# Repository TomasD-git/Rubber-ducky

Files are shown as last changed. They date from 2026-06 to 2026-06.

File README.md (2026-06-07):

# Rubber Ducky  

## Small Rubber Ducky, supports standard rubber ducky code, with website interface.  

## Features:  
**Supports standard rubber ducky code**  
**Website interface over wifi**  
**Pretty small**  
**Wifi + Bluetooth**

<details>
<summary>How to make?</summary>
  
First buy PCB, with stencil if u dont trust your soldering skills or without if u do.
then all components in the bom, u can skip solder paste, kapton tape, hot air station if u have these, once arrived 3D print case solder 4 core cable, plug usbc into pc, flash and then just assemble and you are ready.

</details>

<details>
<summary>BOM</summary>

| Name | Purpose | Quantity | Total Cost (USD) | Distributor |
|---|---|---|---|---|
| [Hot air station](https://www.aliexpress.com/item/1005007009985561.html) | Will solder everything with this | 1 | $39.54 | Aliexpress |
| [PCB + Stencil](https://jlcpcb.com) | All components are on PCB, stencil for easier soldering | 1 | $15.00 | JLCPCB |
| [All components](https://lcsc.com) | All actual components on PCB | Depends on each part | $55.00 | LCSC |
| [4 core cable](https://www.aliexpress.com/item/1005009355432278.html) | Connects the 2 PCBs together | 1 | $4.00 | Aliexpress |
| [Solder paste](https://www.aliexpress.com/item/1005008590694612.html) | Used for soldering | 1 | $7.19 | Aliexpress |
| [Small set of hot air station nozzles](https://www.aliexpress.com/item/1005002724224923.html) | Much easier to solder with 3mm nozzle instead of the 12mm that comes with the hot air station | 1 | $5.18 | Aliexpress |
| [Kapton Tape](https://www.aliexpress.com/item/1005010348863794.html) | Covers soldered stuff so it doesn't get desoldered | 1 | $2.16 | Aliexpress |

**Estimated Total Cost: $128.07**

</details>

## Pictures:







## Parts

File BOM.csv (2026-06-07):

Name | Purpose | Quantity | Total Cost (USD) | Link | Distributor
Hot air station | Will solder everything with this | 1 | 39.54 | https://www.aliexpress.com/item/1005007009985561.html | Aliexpress
PCB + Stencil | all components are on pcb, stencil for easier soldering | 1 | 15 | https://jlcpcb.com | jlcpcb
All components | all actual components on PCB | depends on each part | 55 | https://lcsc.com | lcsc
4 core cable | conects the 2 pcbs together | 1 | 4 | https://www.aliexpress.com/item/1005009355432278.html | Aliexpress
Solder paste | Used for soldering | 1 | 7.19 | https://www.aliexpress.com/item/1005008590694612.html
Small set of hot air station nozzles | much easier to solder with 3mm nozzle instead of the 12mm that comes with the hot air station | 1 | 5.18 | https://www.aliexpress.com/item/1005002724224923.html
Kapton Tape | Covers soldered stuff, so it doesnt get desoldered | 1 | 2.16 | https://www.aliexpress.com/item/1005010348863794.html | Aliexpress
 | Total Cost | Est. | 128.07

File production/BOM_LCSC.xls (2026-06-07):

JLCPCB BOM Tool - BOM Matching
BOM name：bom-JLCPCB Assembly Order-JLCPCB Assembly Order.xlsx |  |  | Download Time：2026-06-07 18:28:33 |  |  |  | * Our matching results are updated in real-time, but stock and prices may change. If it's been over 24 hours, please re-match before placing your order.
PCB Assembled Qty：5 |  |  | Est. Total Price：62.2239
Your BOM |  |  |  |  | Matched Parts |  |  |  |  |  |  | Order Information
Top Designator | Bottom Designator | Comment | Footprint | JLCPCB Part # | Matches | Part # | Manufacturer | Footprint | Description | Category | Warning | JLCPCB Part # | Product link | Lib Type | Qty | Source | Total Price ($)
AE1 |  | 2450AT18A100E | ANT-SMD_L3.2-W1.6 |  | Select by System | 2450AT18A100E | Johanson Dielectrics | 1206 | -40℃~+125℃ 0.5dBi 1.3mm 1.6mm 2.4GHz 2W 3.2mm 50Ω Patch Antenna SMA 1206 Antennas ROHS | Antennas |  | C89334 | https://jlcpcb.com/partdetail/JohansonDielectrics-2450AT18A100E/C89334 | Extended | 5 | 5 JLCPCB | 2.613
 | C10,C14,C3,C4,C7 | 1uF | 0805 |  | Select by System | CL21B105KBFNNNE | Samsung Electro-Mechanics | 0805 | 1uF 50V X7R ±10% 0805 Multilayer Ceramic Capacitors MLCC - SMD/SMT ROHS | Multilayer Ceramic Capacitors MLCC - SMD/SMT |  | C28323 | https://jlcpcb.com/partdetail/29074-CL21B105KBFNNNE/C28323 | Basic | 35 | 35 JLCPCB | 0.665
 | C15,C8,C9 | 10uF | 1206 |  | Select by System | CL31A106KBHNNNE | Samsung Electro-Mechanics | 1206 | 10uF 50V X5R ±10% 1206 Multilayer Ceramic Capacitors MLCC - SMD/SMT ROHS | Multilayer Ceramic Capacitors MLCC - SMD/SMT |  | C13585 | https://jlcpcb.com/partdetail/14236-CL31A106KBHNNNE/C13585 | Basic | 19 | 19 JLCPCB | 1.7385
 | C17 | 10nF | 0402 |  | Select by System | CL05B103KB5NNNC | Samsung Electro-Mechanics | 0402 | 10nF 50V X7R ±10% 0402 Multilayer Ceramic Capacitors MLCC - SMD/SMT ROHS | Multilayer Ceramic Capacitors MLCC - SMD/SMT |  | C15195 | https://jlcpcb.com/partdetail/15869-CL05B103KB5NNNC/C15195 | Basic | 20 | 20 JLCPCB | 0.038
C18,C19 |  | 12pF | 0402 |  | Select by System | 0402CG120J500NT | FH (Guangdong Fenghua Advanced Tech) | 0402 | 12pF 50V C0G ±5% 0402 Multilayer Ceramic Capacitors MLCC - SMD/SMT ROHS | Multilayer Ceramic Capacitors MLCC - SMD/SMT |  | C1547 | https://jlcpcb.com/partdetail/1899-0402CG120J500NT/C1547 | Basic | 20 | 20 JLCPCB | 0.034
C20,C21 |  | 1.5pF | 0402 |  | Select by System | 0402CG1R5C500NT | FH (Guangdong Fenghua Advanced Tech) | 0402 | 1.5pF 50V C0G 0402 Multilayer Ceramic Capacitors MLCC - SMD/SMT ROHS | Multilayer Ceramic Capacitors MLCC - SMD/SMT |  | C1552 | https://jlcpcb.com/partdetail/1904-0402CG1R5C500NT/C1552 | Extended | 20 | 20 JLCPCB | 0.034
C22 |  | 1.2pF | 0402 |  | Select by System | 0402CG1R2C500NT | FH (Guangdong Fenghua Advanced Tech) | 0402 | 1.2pF 50V C0G 0402 Multilayer Ceramic Capacitors MLCC - SMD/SMT ROHS | Multilayer Ceramic Capacitors MLCC - SMD/SMT |  | C1551 | https://jlcpcb.com/partdetail/1903-0402CG1R2C500NT/C1551 | Extended | 20 | 20 JLCPCB | 0.032
C23 |  | 0.5pF | 0402 |  | Select by System | 0402CG0R5C500NT | FH (Guangdong Fenghua Advanced Tech) | 0402 | 0.5pF 50V C0G 0402 Multilayer Ceramic Capacitors MLCC - SMD/SMT ROHS | Multilayer Ceramic Capacitors MLCC - SMD/SMT |  | C1544 | https://jlcpcb.com/partdetail/1896-0402CG0R5C500NT/C1544 | Extended | 20 | 20 JLCPCB | 0.022
C24 |  | 100uF | 1210 |  | Select by System | 1210X107M100NT | FH (Guangdong Fenghua Advanced Tech) | 1210 | 100uF 10V X5R ±20% 1210 Multilayer Ceramic Capacitors MLCC - SMD/SMT ROHS | Multilayer Ceramic Capacitors MLCC - SMD/SMT |  | C19269967 | https://jlcpcb.com/partdetail/20533754-1210X107M100NT/C19269967 | Extended | 5 | 5 JLCPCB | 2.46
C25 | C1,C11,C12,C13,C16,C2,C5,C6 | 100nF | 0603 |  | Select by System | CC0603KRX7R9BB104 | YAGEO | 0603 | 100nF 50V X7R ±10% 0603 Multilayer Ceramic Capacitors MLCC - SMD/SMT ROHS | Multilayer Ceramic Capacitors MLCC - SMD/SMT |  | C14663 | https://jlcpcb.com/partdetail/YAGEO-CC0603KRX7R9BB104/C14663 | Basic | 70 | 70 JLCPCB | 1.827
 | L1 | 2nH | 0402 |  | Select by System | LQG15HS2N0S02D | Murata Electronics | 0402 | 2nH 6GHz 8@100MHz 900mA 90mΩ 0402 Inductors (SMD) ROHS | Inductors (SMD) |  | C18216 | https://jlcpcb.com/partdetail/MurataElectronics-LQG15HS2N0S02D/C18216 | Extended | 20 | 20 JLCPCB | 0.234
L2 |  | 24nH | 0603 |  | Select by System | VHF160808H24NJT | FH (Guangdong Fenghua Advanced Tech) | 0603 | 12@100MHz 24nH 2GHz 300mA 600mΩ Multilayer inductor、High-frequency inductor ±5% 0603 Inductors (SMD) ROHS | Inductors (SMD) |  | C139271 | https://jlcpcb.com/partdetail/150592-VHF160808H24NJT/C139271 | Extended | 20 | 20 JLCPCB | 0.288
L3 |  | 2.7nH | 0402 |  | Select by System | MLG1005S2N7BT000 | TDK | 0402 | 2.7nH 6GHz 7@100MHz 800mA 80mΩ Multilayer inductor 0402 Inductors (SMD) ROHS | Inductors (SMD) |  | C275282 | https://jlcpcb.com/partdetail/TDK-MLG1005S2N7BT000/C275282 | Extended | 20 | 20 JLCPCB | 0.218
L4 |  | 3.9nH | 0402 |  | Select by System | SDCL1005C3N9STDF | Sunlord | 0402 | 200mΩ 3.9nH 300mA 4GHz 8@100MHz Multilayer inductor 0402 Inductors (SMD) ROHS | Inductors (SMD) |  | C14033 | https://jlcpcb.com/partdetail/Sunlord-SDCL1005C3N9STDF/C14033 | Extended | 20 | 20 JLCPCB | 0.118
R1 |  | 5.1K | 0805 |  | Unconfirmed | 0805W8F5101T5E | UNI-ROYAL(Uniroyal Elec) | 0805 | -55℃~+155℃ 125mW 150V 5.1kΩ Thick Film Resistor ±1% ±100ppm/℃ 0805 Chip Resistor - Surface Mount ROHS | Chip Resistor - Surface Mount | 1.The comment (0805W8F5101T5E) of this part does not match the one (5.1K) provided in your BOM. Please confirm; | C27834 | https://jlcpcb.com/partdetail/28584-0805W8F5101T5E/C27834 | Basic | 20 | 20 JLCPCB | 0.054
R2,R3 |  | 22 | 0603 |  | Unconfirmed | 0603WAF220JT5E | UNI-ROYAL(Uniroyal Elec) | 0603 | -55℃~+155℃ 100mW 22Ω 75V Thick Film Resistor ±1% ±100ppm/℃ 0603 Chip Resistor - Surface Mount ROHS | Chip Resistor - Surface Mount | 1.The comment (0603WAF220JT5E) of this part does not match the one (22) provided in your BOM. Please confirm; | C23345 | https://jlcpcb.com/partdetail/24078-0603WAF220JT5E/C23345 | Basic | 20 | 20 JLCPCB | 0.032
 | R10,R12,R13,R4,R5 | 10K | 0805 |  | Unconfirmed | 0805W8F1002T5E | UNI-ROYAL(Uniroyal Elec) | 0805 | -55℃~+155℃ 10kΩ 125mW 150V Thick Film Resistor ±1% ±100ppm/℃ 0805 Chip Resistor - Surface Mount ROHS | Chip Resistor - Surface Mount | 1.The comment (0805W8F1002T5E) of this part does not match the one (10K) provided in your BOM. Please confirm; | C17414 | https://jlcpcb.com/partdetail/18102-0805W8F1002T5E/C17414 | Basic | 35 | 35 JLCPCB | 0.1015
 | U1 | W25Q32JVSSIQ_C179173 | SOIC-8_L5.3-W5.3-P1.27-LS8.0-BL |  | Select by System | W25Q32JVSSIQ | Winbond Elec | SOIC-8-208mil | -40℃~+85℃ 100,000 cycles 133MHz 1uA 2.7V~3.6V 20 Years 32Mbit 3ms SPI SOIC-8-208mil NOR FLASH ROHS | NOR FLASH |  | C179173 | https://jlcpcb.com/partdetail/WinbondElec-W25Q32JVSSIQ/C179173 | Extended | 5 | 5 JLCPCB | 8.2085
U2 |  | ESP32-S3 | QFN-56-1EP_7x7mm_P0.4mm_EP5.6x5.6mm |  | Select by System | ESP32-S3 | Espressif Systems | QFN-56-EP(7x7) | -40℃~+105℃ -98.4dBm 150Mbps 2.412GHz~2.484GHz 2.4GHz 21dBm 340mA 3V~3.6V 88mA SPI、USB、UART、ADC、I2C、I2S、PWM WiFi transceiver QFN-56-EP(7x7) RF Transceiver ICs ROHS | RF Transceiver ICs |  | C2913192 | https://jlcpcb.com/partdetail/EspressifSystems-ESP32S3/C2913192 | Extended | 5 | 5 JLCPCB | 15.259
 | U3 | RT9013-33GB | SOT-23-5_L3.0-W1.7-P0.95-LS2.8-BL |  | Select by System | RT9013-33GB | Richtek Tech | SOT-23-5 | -40℃~+125℃@(Tj) 1 25uA 3.3V 30uVrms 400mV@(500mA) 5.5V 500mA 50dB@(10kHz) Fixed Over Current Protection、Over Temperature Protection、Enable Positive SOT-23-5 Voltage Regulators - Linear, Low Drop Out (LDO) Regulators ROHS | Voltage Regulators - Linear, Low Drop Out (LDO) Regulators |  | C47773 | https://jlcpcb.com/partdetail/RichtekTech-RT901333GB/C47773 | Extended | 7 | 7 JLCPCB | 0.9471
U4 |  | XUSM-0930-2319 | USB-A-SMD_XUSM-0930-2319 |  | Select by System | XUSM-0930-2319 | Lian Xin Technology | SMD | -40℃~+85℃ 1 18.75mm 36V 3A 9P Male Surface Mount, Right Angle Type-A USB 3.0 SMD USB Connectors ROHS | USB Connectors |  | C7527682 | https://jlcpcb.com/partdetail/Lian_XinTechnology-XUSM_09302319/C7527682 | Extended | 5 | 5 JLCPCB | 1.216
U6,U8 |  | SS24FL_C894433 | SOD-123FL_L2.8-W1.8-LS3.6-RD |  | Select by System | SS24FL | onsemi | SOD-123F | -55℃~+125℃ 1 Independent 100uA@40V 2A 40V 50A 550mV@2A SOD-123F Schottky Diodes ROHS | Schottky Diodes |  | C894433 | https://jlcpcb.com/partdetail/onsemi-SS24FL/C894433 | Extended | 10 | 10 JLCPCB | 1.72
U7 |  | W25Q256JVEIQTR | WSON-8_L8.0-W6.10-P1.27-BL-EP |  | Select by System | W25Q256JVEIQ | Winbond Elec | WSON-8-EP(6x8) | -40℃~+85℃ 100,000 cycles 10uA 120ms@(32KB) 133MHz 2.7V~3.6V 20 Years 256Mbit 700us SPI WSON-8-EP(6x8) NOR FLASH ROHS | NOR FLASH |  | C97522 | https://jlcpcb.com/partdetail/WinbondElec-W25Q256JVEIQ/C97522 | Extended | 5 | 5 JLCPCB | 21.12
USB2 |  | GT-USB-8016B | USB-SMD_GT-USB-8016B |  | Select by System | GT-USB-8016B | G-Switch | SMD | -40℃~+85℃ 0.15mm 1 10,000 Cycles 12.2mm 12P Black Laminated board Male Type-C USB 2.0 SMD USB Connectors ROHS | USB Connectors |  | C3001295 | https://jlcpcb.com/partdetail/GSwitch-GT_USB8016B/C3001295 | Extended | 5 | 5 JLCPCB | 2.581
Y1 |  | 40MHz | Crystal_SMD_3225-4Pin_3.2x2.5mm_HandSoldering |  | Select by Customer | HY40MSMD3225GB1R30 | Huiyuan crystal | SMD3225-4P | -40℃~+85℃ 15pF 40MHz 40Ω Crystal Oscillator ±10ppm ±30ppm SMD3225-4P Crystals ROHS | Crystals |  | C5265885 | https://jlcpcb.com/partdetail/Huiyuancrystal-HY40MSMD3225GB1R30/C5265885 | Extended | 9 | 9 JLCPCB | 0.6633

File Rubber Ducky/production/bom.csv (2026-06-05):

Designator | Footprint | Quantity | Value | LCSC Part #
AE1 | ANT-SMD_L3.2-W1.6 | 1 | 2450AT18A100E | C89334
C1, C11, C12, C13, C16, C2, C25, C5, C6 | 0603 | 9 | 100nF
C10, C14, C3, C4, C7 | 0805 | 5 | 1uF
C15, C8, C9 | 1206 | 3 | 10uF
C17 | 0402 | 1 | 10nF
C18, C19 | 0402 | 2 | 12pF
C20, C21 | 0402 | 2 | 1.5pF
C22 | 0402 | 1 | 1.2pF
C23 | 0402 | 1 | 0.5pF
C24 | 1210 | 1 | 100uF
L1 | 0402 | 1 | 2nH
L2 | 0603 | 1 | 24nH
L3 | 0402 | 1 | 2.7nH
L4 | 0402 | 1 | 3.9nH
R1 | 0805 | 1 | 5.1K
R10, R12, R13, R4, R5 | 0805 | 5 | 10K
R2, R3 | 0603 | 2 | 22
U1 | SOIC-8_L5.3-W5.3-P1.27-LS8.0-BL | 1 | W25Q32JVSSIQ_C179173 | C179173
U2 | QFN-56-1EP_7x7mm_P0.4mm_EP5.6x5.6mm | 1 | ESP32-S3
U3 | SOT-23-5_L3.0-W1.7-P0.95-LS2.8-BL | 1 | RT9013-33GB | C47773
U4 | USB-A-SMD_XUSM-0930-2319 | 1 | XUSM-0930-2319 | C7527682
U6, U8 | SOD-123FL_L2.8-W1.8-LS3.6-RD | 2 | SS24FL_C894433 | C894433
U7 | WSON-8_L8.0-W6.10-P1.27-BL-EP | 1 | W25Q256JVEIQTR | C97522
USB2 | USB-SMD_GT-USB-8016B | 1 | GT-USB-8016B | C3001295
Y1 | Crystal_SMD_3225-4Pin_3.2x2.5mm_HandSoldering | 1 | 40MHz

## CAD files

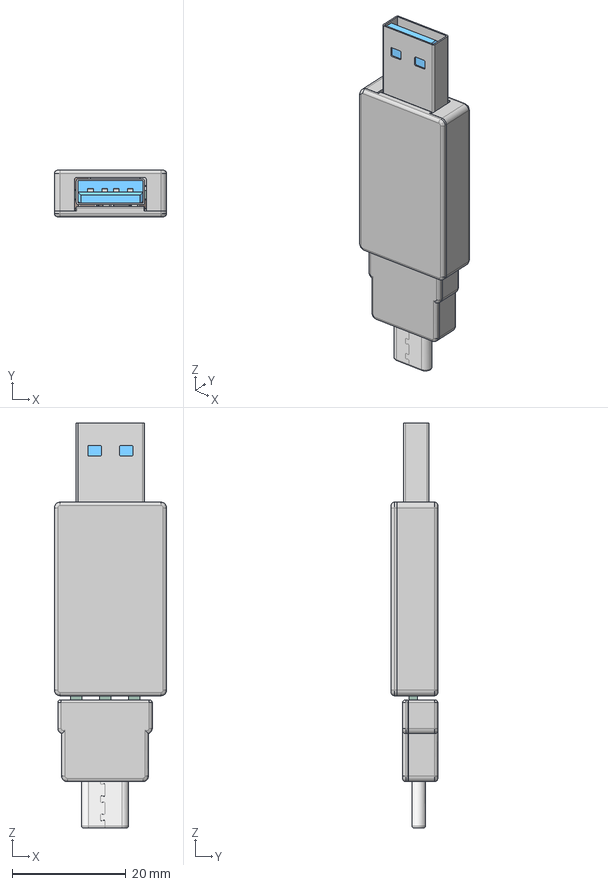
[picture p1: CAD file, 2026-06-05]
CAD/Full_Rubber_Ducky.step
19.7 x 8.21 x 71.1 mm
Crystal_SMD_3225-4Pin_3.2x2.5mm
WSON-8_L8.0-W6.0-H0.78-P1.27
C_0402_1005Metric x 7
C_1210_3225Metric
QFN-56-1EP_7x7mm_P0.4mm_EP5.6x5.6mm
R_0603_1608Metric x 2
R_0805_2012Metric x 6
L_0603_1608Metric
USB-A-SMD_XUSM-0930-2319
SOD-123FL_L2.8-W1.8-LS3.6-RD x 2
L_0402_1005Metric x 3
ANT-SMD_L3.2-W1.6-H1.3
C_0603_1608Metric x 9
USB-SMD_GT-USB-8016B
SOT-23-5_L2.9-W1.6-H1.1-LS2.8-P0.95
C_0805_2012Metric x 5
SOIC-8_L5.3-W5.3-H1.9-LS7.9-P1.27
C_1206_3216Metric x 3
Metal Ducky_PCB

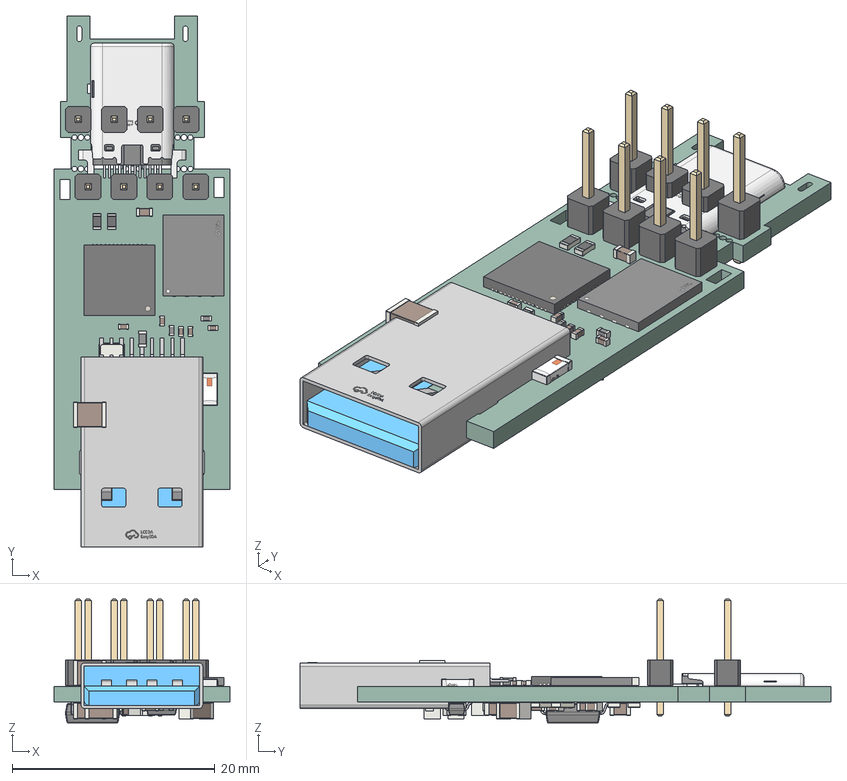
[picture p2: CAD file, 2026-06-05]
CAD/Rubber ducky_PCB.step
17.3 x 52.3 x 12.2 mm
Crystal_SMD_3225-4Pin_3.2x2.5mm
PinHeader_1x01_P2.54mm_Vertical x 8
WSON-8_L8.0-W6.0-H0.78-P1.27
C_0402_1005Metric x 7
C_1210_3225Metric
QFN-56-1EP_7x7mm_P0.4mm_EP5.6x5.6mm
R_0603_1608Metric x 2
R_0805_2012Metric x 6
L_0603_1608Metric
USB-A-SMD_XUSM-0930-2319
SOD-123FL_L2.8-W1.8-LS3.6-RD x 2
L_0402_1005Metric x 3
ANT-SMD_L3.2-W1.6-H1.3
C_0603_1608Metric x 9
USB-SMD_GT-USB-8016B
SOT-23-5_L2.9-W1.6-H1.1-LS2.8-P0.95
C_0805_2012Metric x 5
SOIC-8_L5.3-W5.3-H1.9-LS7.9-P1.27
C_1206_3216Metric x 3
Metal Ducky_PCB

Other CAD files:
CAD/Full_Rubber_Ducky.f3z

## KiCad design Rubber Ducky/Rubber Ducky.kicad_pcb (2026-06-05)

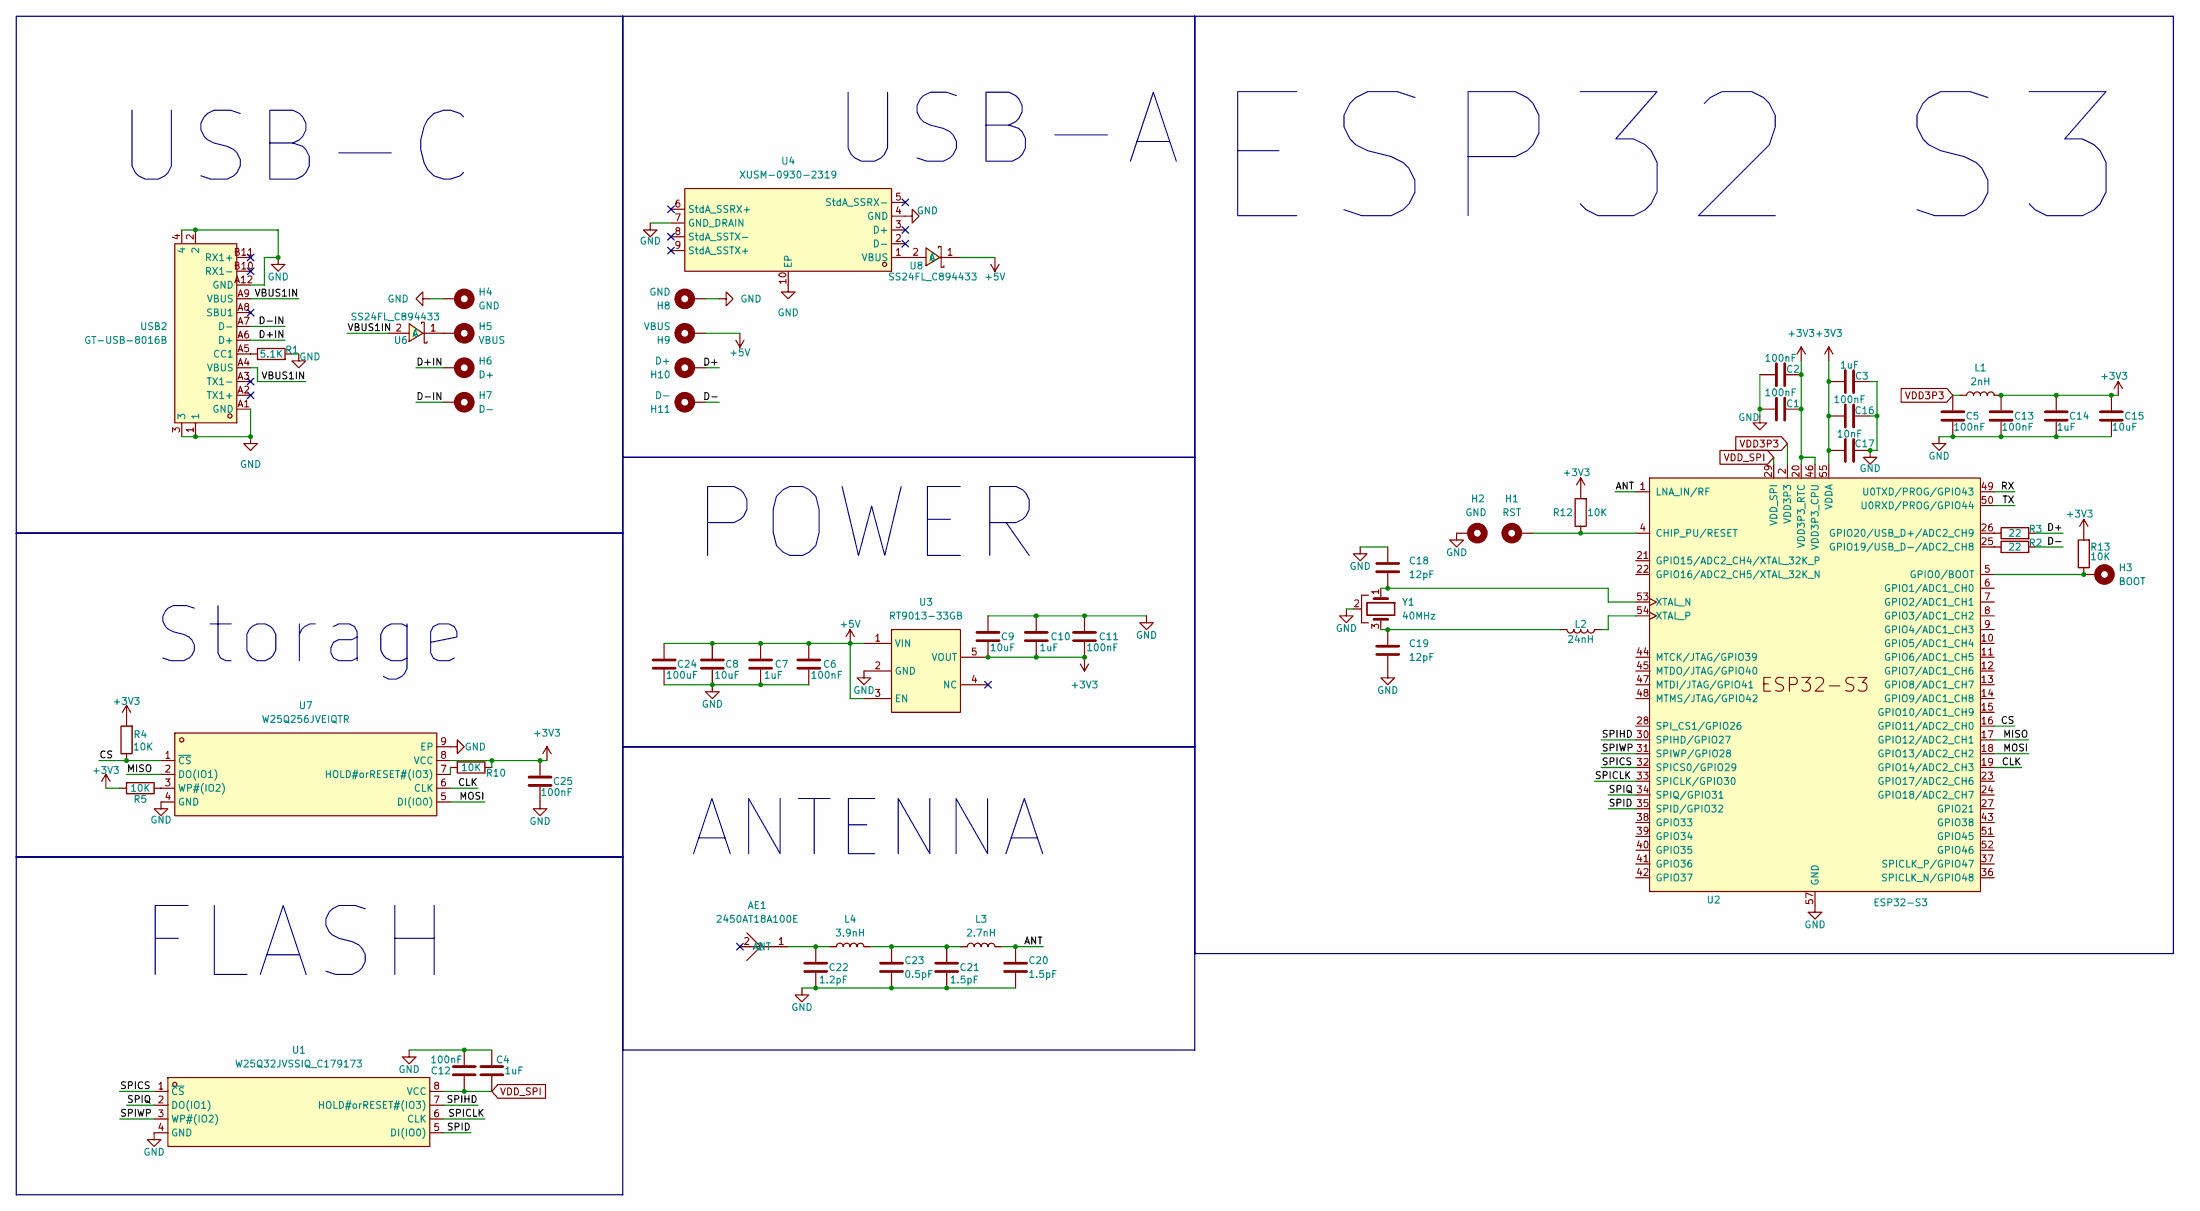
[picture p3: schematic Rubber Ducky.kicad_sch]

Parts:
AE1: 2450AT18A100E; ANT-SMD_L3.2-W1.6; MPN 2450AT18A100E; LCSC Part C89334
C1, C2, C5, C6, C11, C12, C13, C16, C25: 100nF; C_0603_1608Metric_Pad1.08x0.95mm_HandSolder
C3, C4, C7: 1uF; C_0805_2012Metric
C8, C9, C15: 10uF; C_1206_3216Metric
C10, C14: 1uF; C_0805_2012Metric_Pad1.18x1.45mm_HandSolder
C17: 10nF; C_0402_1005Metric_Pad0.74x0.62mm_HandSolder
C18, C19: 12pF; C_0402_1005Metric_Pad0.74x0.62mm_HandSolder
C20, C21: 1.5pF; C_0402_1005Metric_Pad0.74x0.62mm_HandSolder
C22: 1.2pF; C_0402_1005Metric_Pad0.74x0.62mm_HandSolder
C23: 0.5pF; C_0402_1005Metric_Pad0.74x0.62mm_HandSolder
C24: 100uF; C_1210_3225Metric
H1: RST; TestPoint_Pad_1.0x1.0mm
H2: GND; TestPoint_Pad_1.0x1.0mm
H3: BOOT; TestPoint_Pad_1.0x1.0mm
H4, H8: GND; PinHeader_1x01_P2.54mm_Vertical
H5, H9: VBUS; PinHeader_1x01_P2.54mm_Vertical
H6, H10: D+; PinHeader_1x01_P2.54mm_Vertical
H7, H11: D-; PinHeader_1x01_P2.54mm_Vertical
L1: 2nH; L_0402_1005Metric_Pad0.77x0.64mm_HandSolder
L2: 24nH; L_0603_1608Metric_Pad1.05x0.95mm_HandSolder
L3: 2.7nH; L_0402_1005Metric_Pad0.77x0.64mm_HandSolder
L4: 3.9nH; L_0402_1005Metric_Pad0.77x0.64mm_HandSolder
R1: 5.1K; R_0805_2012Metric
R2, R3: 22; R_0603_1608Metric_Pad0.98x0.95mm_HandSolder
R4, R5, R10, R12, R13: 10K; R_0805_2012Metric
U1: W25Q32JVSSIQ_C179173; SOIC-8_L5.3-W5.3-P1.27-LS8.0-BL; MPN W25Q32JVSSIQ; LCSC Part C179173
U2: ESP32-S3; QFN-56-1EP_7x7mm_P0.4mm_EP5.6x5.6mm
U3: RT9013-33GB; SOT-23-5_L3.0-W1.7-P0.95-LS2.8-BL; MPN RT9013-33GB; LCSC Part C47773
U4: XUSM-0930-2319; USB-A-SMD_XUSM-0930-2319; MPN XUSM-0930-2319; LCSC Part C7527682
U6, U8: SS24FL_C894433; SOD-123FL_L2.8-W1.8-LS3.6-RD; MPN SS24FL; LCSC Part C894433
U7: W25Q256JVEIQTR; WSON-8_L8.0-W6.10-P1.27-BL-EP; MPN W25Q256JVEIQ; LCSC Part C97522
USB2: GT-USB-8016B; USB-SMD_GT-USB-8016B; MPN GT-USB-8016B; LCSC Part C3001295
Y1: 40MHz; Crystal_SMD_3225-4Pin_3.2x2.5mm_HandSoldering

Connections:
+3V3: C1.2, C2.2, C3.1, C9.2, C10.2, C11.2, C13.1, C14.1, C15.1, C16.1, C17.1, C25.1, L1.2, R4.2, R5.2, R10.1, R12.2, R13.2, U2.20 (VDD3P3_RTC), U2.46 (VDD3P3_CPU), U2.55 (VDDA), U2.56 (VDDA), U3.5 (VOUT), U7.8 (VCC)
+5V: C6.1, C7.1, C8.1, C24.1, H9.1, U3.1 (VIN), U3.3 (EN), U8.1 (C)
/ANT: C20.1, L3.2, U2.1 (LNA_IN/RF)
/CLK: U2.19 (GPIO14/ADC2_CH3), U7.6 (CLK)
/CS: R4.1, U2.16 (GPIO11/ADC2_CH0), U7.1 (~CS)
/D+: H10.1, R3.2
/D+IN: H6.1, USB2.A6 (D+)
/D-: H11.1, R2.2
/D-IN: H7.1, USB2.A7 (D-)
/MISO: U2.17 (GPIO12/ADC2_CH1), U7.2 (DO(IO1))
/MOSI: U2.18 (GPIO13/ADC2_CH2), U7.5 (DI(IO0))
/RX: U2.49 (U0TXD/PROG/GPIO43)
/SPICLK: U1.6 (CLK), U2.33 (SPICLK/GPIO30)
/SPICS: U1.1 (~CS), U2.32 (SPICS0/GPIO29)
/SPID: U1.5 (DI(IO0)), U2.35 (SPID/GPIO32)
/SPIHD: U1.7 (HOLD#orRESET#(IO3)), U2.30 (SPIHD/GPIO27)
/SPIQ: U1.2 (DO(IO1)), U2.34 (SPIQ/GPIO31)
/SPIWP: U1.3 (WP#(IO2)), U2.31 (SPIWP/GPIO28)
/TX: U2.50 (U0RXD/PROG/GPIO44)
/VBUS1IN: U6.2 (A), USB2.A4 (VBUS), USB2.A9 (VBUS)
GND: C1.1, C2.1, C3.2, C4.2, C5.2, C6.2, C7.2, C8.2, C9.1, C10.1, C11.1, C12.2, C13.2, C14.2, C15.2, C16.2, C17.2, C18.1, C19.2, C20.2, C21.2, C22.2, C23.2, C24.2, C25.2, H2.1, H4.1, H8.1, R1.2, U1.4 (GND), U2.57 (GND), U3.2 (GND), U4.4 (GND), U4.7 (GND_DRAIN), U4.10 (EP), U7.4 (GND), U7.9 (EP), USB2.1, USB2.2, USB2.3, USB2.4, USB2.A1 (GND), USB2.A12 (GND), Y1.2
unnamed: AE1.1 (ANT), C22.1, L4.1
unnamed: C19.1, L2.2, Y1.3
unnamed: C21.1, C23.1, L3.1, L4.2
unnamed: H1.1, R12.1, U2.4 (CHIP_PU/RESET)
unnamed: H3.1, R13.1, U2.5 (GPIO0/BOOT)
unnamed: R2.1, U2.25 (GPIO19/USB_D-/ADC2_CH8)
unnamed: R3.1, U2.26 (GPIO20/USB_D+/ADC2_CH9)
unnamed: C18.2, U2.53 (XTAL_N), Y1.1
unnamed: L2.1, U2.54 (XTAL_P)
unnamed: U4.1 (VBUS), U8.2 (A)
unnamed: H5.1, U6.1 (C)
unnamed: R10.2, U7.7 (HOLD#orRESET#(IO3))
unnamed: R5.1, U7.3 (WP#(IO2))
unnamed: R1.1, USB2.A5 (CC1)
VDD3P3: C5.1, L1.1, U2.2 (VDD3P3), U2.3 (VDD3P3)
VDD_SPI: C4.1, C12.1, U1.8 (VCC), U2.29 (VDD_SPI)

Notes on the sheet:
Storage
ANTENNA
USB-C
POWER
ESP32 S3
USB-A
FLASH

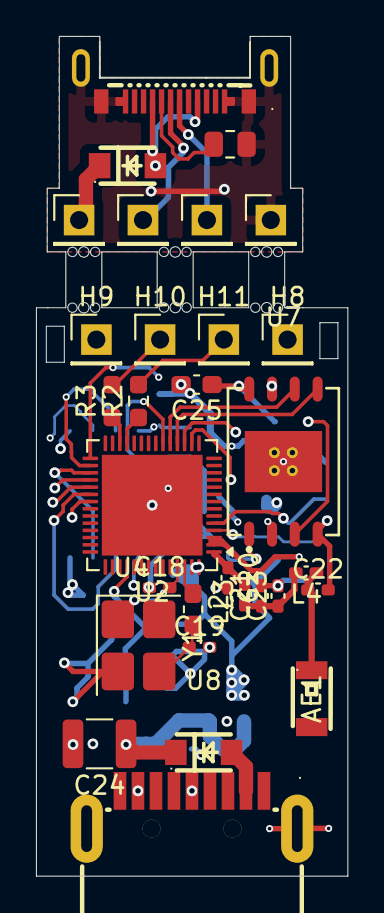
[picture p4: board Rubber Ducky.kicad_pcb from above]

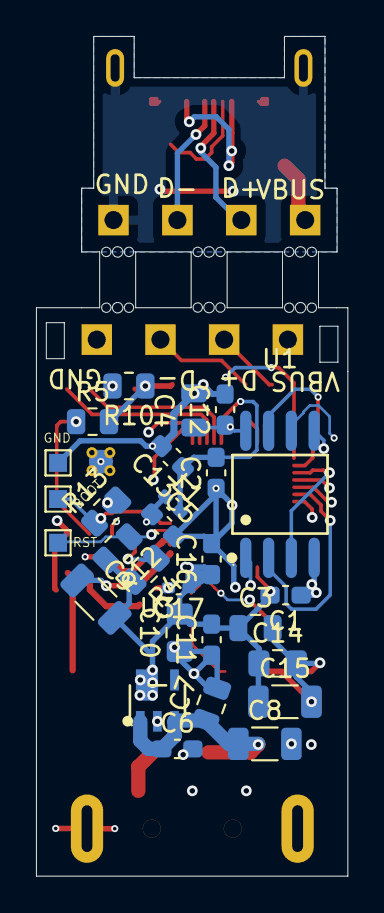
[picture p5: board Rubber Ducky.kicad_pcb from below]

Board: 4 copper layers, 17.3 x 46.6 mm, 58 parts (28 on the bottom side), 35 nets.

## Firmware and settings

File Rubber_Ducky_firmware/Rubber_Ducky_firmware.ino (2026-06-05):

#include <WiFi.h>
#include <WebServer.h>
#include <SPIFFS.h>
#include <Preferences.h>
#include <ArduinoJson.h>
#include <USB.h>
#include <USBHIDKeyboard.h>

WebServer server(80);
Preferences prefs;
USBHIDKeyboard keyboard;

bool scriptRunning = false;
unsigned long scriptStartTime = 0;

struct Config {
  char ssid[32];
  char password[32];
  char deviceName[32];
  bool apMode;
  int apChannel;
  uint16_t defaultDelay;
} config;

const char* AP_SSID_DEFAULT = "RubberDucky";
const char* AP_PASSWORD_DEFAULT = "12345678";
const int AP_CHANNEL_DEFAULT = 6;
const int AP_MAX_CONNECTIONS = 1;

// USB HID KEYBOARD SETUP
void initUSBHID() {
  keyboard.begin();
  USB.manufacturerName("Microsoft");
  USB.productName("USB Keyboard");
  USB.begin();
  Serial.println("[USB] HID Keyboard initialized");
}

struct KeyInfo {
  const char* name;
  uint8_t keycode;
  bool isSpecial; 
};

const KeyInfo specialKeys[] = {
  {"ENTER", KEY_RETURN, true},
  {"RETURN", KEY_RETURN, true},
  {"SPACE", ' ', false},
  {"TAB", KEY_TAB, true},
  {"BACKSPACE", KEY_BACKSPACE, true},
  {"DELETE", KEY_DELETE, true},
  {"INSERT", KEY_INSERT, true},
  {"HOME", KEY_HOME, true},
  {"END", KEY_END, true},
  {"PAGEUP", KEY_PAGE_UP, true},
  {"PAGE_UP", KEY_PAGE_UP, true},
  {"PAGEDOWN", KEY_PAGE_DOWN, true},
  {"PAGE_DOWN", KEY_PAGE_DOWN, true},
  {"UP", KEY_UP_ARROW, true},
  {"DOWN", KEY_DOWN_ARROW, true},
  {"LEFT", KEY_LEFT_ARROW, true},
  {"RIGHT", KEY_RIGHT_ARROW, true},
  {"ESCAPE", KEY_ESC, true},
  {"ESC", KEY_ESC, true},
  {"CAPSLOCK", KEY_CAPS_LOCK, true},
  {"NUMLOCK", KEY_NUM_LOCK, true},
  {"SCROLLLOCK", KEY_SCROLL_LOCK, true},
  {"PRINTSCREEN", KEY_PRINT_SCREEN, true},
  {"PAUSE", KEY_PAUSE, true},
  {"BREAK", KEY_PAUSE, true},
  {"F1", KEY_F1, true},
  {"F2", KEY_F2, true},
  {"F3", KEY_F3, true},
  {"F4", KEY_F4, true},
  {"F5", KEY_F5, true},
  {"F6", KEY_F6, true},
  {"F7", KEY_F7, true},
  {"F8", KEY_F8, true},
  {"F9", KEY_F9, true},
  {"F10", KEY_F10, true},
  {"F11", KEY_F11, true},
  {"F12", KEY_F12, true},
  {nullptr, 0, false}
};

uint8_t getKeyCode(const char* keyName) {
  for (int i = 0; specialKeys[i].name != nullptr; i++) {
    if (strcmp(keyName, specialKeys[i].name) == 0) {
      return specialKeys[i].keycode;
    }
  }
  if (strlen(keyName) == 1) {
    return (uint8_t)keyName[0];
  }
  return 0;
}

uint8_t getModifierByte(const char* modName) {
  if (strcmp(modName, "CTRL") == 0 || strcmp(modName, "CONTROL") == 0) return KEY_LEFT_CTRL;
  if (strcmp(modName, "SHIFT") == 0) return KEY_LEFT_SHIFT;
  if (strcmp(modName, "ALT") == 0) return KEY_LEFT_ALT;
  if (strcmp(modName, "GUI") == 0 || strcmp(modName, "WINDOWS") == 0 || 
      strcmp(modName, "COMMAND") == 0) return KEY_LEFT_GUI;
  return 0;
}

void executeDuckyScript(const String& scriptContent) {
  if (scriptRunning) {
    Serial.println("[Script] Another script running");
    return;
  }
  
  scriptRunning = true;
  scriptStartTime = millis();
  Serial.println("[Script] Starting");
  
  char* scriptBuf = (char*)malloc(scriptContent.length() + 1);
  if (!scriptBuf) {
    scriptRunning = false;
    return;
  }
  strcpy(scriptBuf, scriptContent.c_str());
  
  char* line = strtok(scriptBuf, "\n");
  int lineNum = 0;
  uint16_t defaultDelay = config.defaultDelay;
  char lastCommand[512] = {0};
  
  while (line && scriptRunning) {
    lineNum++;
    
    int len = strlen(line);
    while (len > 0 && (line[len-1] == '\r' || line[len-1] == ' ')) {
      line[--len] = '\0';
    }
    while (len > 0 && (line[0] == ' ' || line[0] == '\t')) {
      line++;
      len--;
    }
    if (len == 0) {
      line = strtok(nullptr, "\n");
      continue;
    }
    char cmdBuf[512];
    strcpy(cmdBuf, line);
    for (int i = 0; cmdBuf[i]; i++) cmdBuf[i] = toupper(cmdBuf[i]);
    if (strncmp(cmdBuf, "REPEAT ", 7) == 0) {
      int repeatCount = atoi(cmdBuf + 7);
      for (int r = 0; r < repeatCount && scriptRunning; r++) {
        if (strlen(lastCommand) > 0) {
          char lastCopy[512];
          strcpy(lastCopy, lastCommand);
          char* lastCmdBuf = strtok(lastCopy, " ");
          if (lastCmdBuf) {
            char cmdUp[64];
            strcpy(cmdUp, lastCmdBuf);
            for (int i = 0; cmdUp[i]; i++) cmdUp[i] = toupper(cmdUp[i]);
            if (strcmp(cmdUp, "STRING") == 0) {
              char* arg = lastCmdBuf + 6;
              while (*arg == ' ') arg++;
              keyboard.print(arg);
            } else if (strcmp(cmdUp, "DELAY") == 0) {
              int ms = atoi(lastCmdBuf + 5);
              delay(ms);
            }
          }
        }
        if (defaultDelay > 0) delay(defaultDelay);
      }
      line = strtok(nullptr, "\n");
      continue;
    }
    strcpy(lastCommand, line);
    if (strncmp(cmdBuf, "REM", 3) == 0 && (cmdBuf[3] == ' ' || cmdBuf[3] == '\0')) {
      line = strtok(nullptr, "\n");
      continue;
    }
    if (strncmp(cmdBuf, "DEFAULTDELAY ", 13) == 0) {
      defaultDelay = atoi(cmdBuf + 13);
      Serial.printf("[Script] Default delay set to %d ms\n", defaultDelay);
      line = strtok(nullptr, "\n");
      continue;
    }
    if (strncmp(cmdBuf, "DEFAULT_DELAY ", 14) == 0) {
      defaultDelay = atoi(cmdBuf + 14);
      Serial.printf("[Script] Default delay set to %d ms\n", defaultDelay);
      line = strtok(nullptr, "\n");
      continue;
    }

    if (strncmp(cmdBuf, "DELAY ", 6) == 0) {
      int ms = atoi(cmdBuf + 6);
      delay(ms);
      line = strtok(nullptr, "\n");
      continue;
    }

    if (strncmp(cmdBuf, "STRING ", 7) == 0) {
      const char* str = line + 7;
      keyboard.print(str);
      Serial.printf("[Script] Typed: %s\n", str);
      if (defaultDelay > 0) delay(defaultDelay);
      line = strtok(nullptr, "\n");
      continue;
    }
    
    if (strncmp(cmdBuf, "STRINGLN ", 9) == 0) {
      const char* str = line + 9;
      keyboard.print(str);
      keyboard.press(KEY_RETURN);
      keyboard.release(KEY_RETURN);
      if (defaultDelay > 0) delay(defaultDelay);
      line = strtok(nullptr, "\n");
      continue;
    }
// KEY COMBINATIONS
    {
      char* token = strtok(cmdBuf, " ");
      uint8_t modifiers = 0;
      uint8_t finalKey = 0;
      int tokenCount = 0;
      char tokens[16][64];
      int tokenIdx = 0;
      strcpy(cmdBuf, line); 
      token = strtok(cmdBuf, " ");
      while (token && tokenIdx < 16) {
        strcpy(tokens[tokenIdx++], token);
        token = strtok(nullptr, " ");
      }
      for (int i = 0; i < tokenIdx; i++) {
        char keyUp[64];
        strcpy(keyUp, tokens[i]);
        for (int j = 0; keyUp[j]; j++) keyUp[j] = toupper(keyUp[j]);
        uint8_t mod = getModifierByte(keyUp);
        if (mod != 0) {
          modifiers |= mod; 
        } else {
          uint8_t kc = getKeyCode(keyUp);
          if (kc != 0) {
            finalKey = kc;
          }
        }
      }

      if (finalKey != 0 || modifiers != 0) {
        if (modifiers & KEY_LEFT_CTRL) keyboard.press(KEY_LEFT_CTRL);
        if (modifiers & KEY_LEFT_SHIFT) keyboard.press(KEY_LEFT_SHIFT);
        if (modifiers & KEY_LEFT_ALT) keyboard.press(KEY_LEFT_ALT);
        if (modifiers & KEY_LEFT_GUI) keyboard.press(KEY_LEFT_GUI);
        if (finalKey != 0) {
          keyboard.press(finalKey);
        }
        delay(50);
        keyboard.releaseAll();
        delay(50);
        if (finalKey != 0) {
          Serial.printf("[Script] Key combination executed\n");
        }
        if (defaultDelay > 0) delay(defaultDelay);
      }
    }
    line = strtok(nullptr, "\n");
    yield(); 
  } 
  free(scriptBuf);
  scriptRunning = false;
  unsigned long execTime = millis() - scriptStartTime;
}
void initSPIFFS() {
  if (!SPIFFS.begin(true)) {
    Serial.println("Mount Failed");
    return;
  }
  if (!SPIFFS.exists("/scripts")) {
    File dir = SPIFFS.open("/scripts", FILE_WRITE);
    dir.close();
  }
}
void initPreferences() {
  prefs.begin("ducky", false);
}
void loadConfig() {
  strcpy(config.ssid, prefs.getString("ssid", "").c_str());
  strcpy(config.password, prefs.getString("password", "").c_str());
  strcpy(config.deviceName, prefs.getString("deviceName", "RubberDucky").c_str());
  config.apMode = prefs.getBool("apMode", true);
  config.apChannel = prefs.getInt("apChannel", AP_CHANNEL_DEFAULT);
  config.defaultDelay = prefs.getUShort("defaultDelay", 100);
  
  if (strlen(config.ssid) == 0) {
    config.apMode = true;
  }
}

void saveConfig() {
  prefs.putString("ssid", config.ssid);
  prefs.putString("password", config.password);
  prefs.putString("deviceName", config.deviceName);
  prefs.putBool("apMode", config.apMode);
  prefs.putInt("apChannel", config.apChannel);
  prefs.putUShort("defaultDelay", config.defaultDelay);
}

String readFile(const char* path) {
  if (!SPIFFS.exists(path)) return "";
  File file = SPIFFS.open(path, FILE_READ);
  String content = "";
  while (file.available()) {
    content += (char)file.read();
  }
  file.close();
  return content;
}

void writeFile(const char* path, const String& content) {
  File file = SPIFFS.open(path, FILE_WRITE);
  if (file) {
    file.print(content);
    file.close();
    Serial.println(path);
  }
}

void deleteFile(const char* path) {
  if (SPIFFS.exists(path)) {
    SPIFFS.remove(path);
    Serial.println(path);
  }
}

// wifi
void startAPMode() {
  Serial.println("Starting WIFI");
  WiFi.mode(WIFI_AP);
  WiFi.softAP(config.deviceName, AP_PASSWORD_DEFAULT, config.apChannel, 0, AP_MAX_CONNECTIONS);
  IPAddress IP = WiFi.softAPIP();
  Serial.print("Running on: ");
  Serial.println(IP);
}

void startClientMode() {
  WiFi.mode(WIFI_STA);
  WiFi.begin(config.ssid, config.password);
  
  int attempts = 0;
  while (WiFi.status() != WL_CONNECTED && attempts < 20) {
    delay(500);
    Serial.print(".");
    attempts++;
  }
  
  if (WiFi.status() == WL_CONNECTED) {
    Serial.println(WiFi.localIP());
  } else {
    config.apMode = true;
    startAPMode();
  }
}
// website
void handleRoot() {
  String html = R"(
<!DOCTYPE html>
<html>
<head>
  <meta charset="UTF-8">
  <meta name="viewport" content="width=device-width, initial-scale=1.0">
  <title>Rubber Ducky Control</title>
  <style>
    * { margin: 0; padding: 0; box-sizing: border-box; }
    body { font-family: 'Courier New', monospace; background: #1a1a1a; color: #e0e0e0; }
    .container { max-width: 1000px; margin: 20px auto; padding: 0 20px; }
    h1 { color: #00ff88; margin: 30px 0 20px; }
    .nav { background: #222; padding: 15px; border-radius: 5px; margin-bottom: 20px; }
    .nav a { color: #00ff88; text-decoration: none; margin-right: 20px; }
    .nav a:hover { color: #fff; }
    .section { background: #2a2a2a; padding: 20px; border: 1px solid #444; border-radius: 5px; margin-bottom: 20px; }
    .section h2 { color: #00ff88; margin-bottom: 15px; border-bottom: 1px solid #444; padding-bottom: 10px; }
    .form-group { margin-bottom: 15px; }
    label { display: block; margin-bottom: 5px; color: #aaa; font-size: 12px; }
    input, select, textarea { width: 100%; padding: 8px; background: #1e1e1e; color: #e0e0e0; border: 1px solid #444; border-radius: 3px; font-family: monospace; }
    textarea { resize: vertical; min-height: 200px; }
    button { padding: 10px 20px; background: #00ff88; color: #000; border: none; border-radius: 3px; cursor: pointer; font-weight: bold; margin-right: 10px; }
    button:hover { background: #00cc66; }
    button.danger { background: #ff4444; }
    button.danger:hover { background: #ff2222; }
    .script-item { background: #1e1e1e; padding: 12px; margin: 8px 0; border-left: 3px solid #00ff88; border-radius: 3px; }
    .script-item-name { color: #00ff88; font-weight: bold; }
    .script-item-actions button { padding: 5px 10px; font-size: 12px; }
    .status { padding: 10px; margin-bottom: 15px; border-radius: 3px; }
    .status.success { background: #1a3a1a; border: 1px solid #00ff88; color: #00ff88; }
    .status.error { background: #3a1a1a; border: 1px solid #ff4444; color: #ff4444; }
    .status.info { background: #1a2a3a; border: 1px solid #00aaff; color: #00aaff; }
    .executing { color: #ffff00; }
    hr { border: none; border-top: 1px solid #444; margin: 15px 0; }
  </style>
</head>
<body>
  <div class="container">
    <h1>Rubber Ducky Control</h1>
    <div class="nav">
      <a href="/">Dashboard</a>
      <a href="#scripts">Scripts</a>
      <a href="#editor">Editor</a>
      <a href="#config">Settings</a>
    </div>
    
    <div id="status"></div>
    
    <div id="dashboard" class="section">
      <h2>Dashboard</h2>
      <p id="status-text">Loading...</p>
      <hr>
      <button onclick="location.reload()">Refresh</button>
    </div>
    
    <div id="scripts" class="section">
      <h2>Scripts</h2>
      <div id="scriptList"></div>
      <button onclick="refreshScripts()">Refresh List</button>
    </div>
    
    <div id="editor" class="section">
      <h2>Script Editor</h2>
      <div class="form-group">
        <label>Script Name:</label>
        <input type="text" id="scriptName" placeholder="my_script.txt">
      </div>
      <div class="form-group">
        <label>Script Content (DuckyScript format):</label>
        <textarea id="scriptContent" placeholder="REM This is a comment&#10;DELAY 1000&#10;STRING Hello World&#10;ENTER"></textarea>
      </div>
      <button onclick="saveCurrentScript()" style="background: #00ff88;">Save Script</button>
      <button onclick="loadScriptToEditor()" id="editBtn" style="display:none;">Load Selected</button>
      <hr>
      <h3 style="color: #00aa88; margin-top: 20px;">DuckyScript Reference:</h3>
      <pre style="background: #1e1e1e; padding: 10px; border: 1px solid #444; overflow-x: auto; font-size: 11px;">
REM comment              - Comments (ignored)
DELAY [ms]              - Wait milliseconds
STRING text             - Type text
STRINGLN text           - Type text + ENTER
ENTER / RETURN          - Press Enter key
SPACE                   - Press Space
TAB                     - Press Tab
BACKSPACE               - Backspace key
DELETE                  - Delete key
ESCAPE / ESC            - Escape key
HOME / END              - Home/End keys
PAGEUP / PAGEDOWN       - Page up/down
UP / DOWN / LEFT / RIGHT - Arrow keys
F1 to F12               - Function keys
CTRL [key]              - Hold CTRL + key
SHIFT [key]             - Hold SHIFT + key
ALT [key]               - Hold ALT + key
GUI [key]               - Hold Windows key
CAPSLOCK / NUMLOCK      - Lock keys
DEFAULTDELAY [ms]       - Set delay between commands
REPEAT [n]              - Repeat last command n times
      </pre>
    </div>
    
    <div id="config" class="section">
      <h2>Settings</h2>
      <div class="form-group">
        <label>Device Name:</label>
        <input type="text" id="deviceName" placeholder="RubberDucky">
      </div>
      <div class="form-group">
        <label>Default Command Delay (ms):</label>
        <input type="number" id="defaultDelay" value="100" min="0" max="10000">
      </div>
      <div class="form-group">
        <label>Mode:</label>
        <select id="mode">
          <option value="ap">Access Point (AP)</option>
          <option value="client">Client Mode (WiFi)</option>
        </select>
      </div>
      <div id="clientSettings" style="display:none;">
        <div class="form-group">
          <label>WiFi SSID:</label>
          <input type="text" id="ssid">
        </div>
        <div class="form-group">
          <label>WiFi Password:</label>
          <input type="password" id="password">
        </div>
      </div>
      <button onclick="saveConfig()" style="background: #00ff88;">Save Settings</button>
    </div>
  </div>

  <script>
    let currentScript = null;
    
    function showStatus(msg, type = 'info') {
      const div = document.getElementById('status');
      div.innerHTML = `<div class="status ${type}">${msg}</div>`;
      setTimeout(() => { div.innerHTML = ''; }, 5000);
    }
    
    function refreshScripts() {
      fetch('/api/scripts')
        .then(r => r.json())
        .then(data => {
          let html = '';
          data.scripts.forEach(name => {
            html += `
              <div class="script-item">
                <div class="script-item-name">${name}</div>
                <div class="script-item-actions">
                  <button onclick="editScript('${name}')">Edit</button>
                  <button onclick="runScript('${name}')">Run</button>
                  <button onclick="deleteScript('${name}')" class="danger">Delete</button>
                </div>
              </div>
            `;
          });
          document.getElementById('scriptList').innerHTML = html || '<p>No scripts found</p>';
        });
    }
    
    function editScript(name) {
      currentScript = name;
      fetch(`/api/scripts/content?name=${name}`)
        .then(r => r.text())
        .then(content => {
          document.getElementById('scriptName').value = name;
          document.getElementById('scriptContent').value = content;
          window.location.hash = '#editor';
        });
    }
    
    function saveCurrentScript() {
      const name = document.getElementById('scriptName').value;
      const content = document.getElementById('scriptContent').value;
      
      if (!name) { showStatus('Enter script name', 'error'); return; }
      
      const formData = new FormData();
      formData.append('name', name);
      formData.append('content', content);
      
      fetch('/api/scripts/content', { method: 'POST', body: formData })
        .then(r => r.json())
        .then(d => {
          showStatus('Script saved!', 'success');
          refreshScripts();
        });
    }
    
    function deleteScript(name) {
      if (!confirm(`Delete "${name}"?`)) return;
      fetch('/api/scripts/delete', {
        method: 'POST',
        headers: { 'Content-Type': 'application/json' },
        body: JSON.stringify({ name })
      })
      .then(r => r.json())
      .then(d => { showStatus('Deleted', 'success'); refreshScripts(); });
    }
    
    function runScript(name) {
      showStatus(`<span class="executing">Running: ${name}</span>`, 'info');
      fetch('/api/scripts/run', {
        method: 'POST',
        headers: { 'Content-Type': 'application/json' },
        body: JSON.stringify({ name })
      })
      .then(r => r.json())
      .then(d => showStatus('Script executed!', 'success'))
      .catch(e => showStatus('Error: ' + e, 'error'));
    }
    
    function saveConfig() {
      const data = {
        deviceName: document.getElementById('deviceName').value,
        defaultDelay: parseInt(document.getElementById('defaultDelay').value),
        apMode: document.getElementById('mode').value === 'ap',
        ssid: document.getElementById('ssid').value,
        password: document.getElementById('password').value,
        apChannel: 6
      };
      
      fetch('/api/config', {
        method: 'POST',
        headers: { 'Content-Type': 'application/json' },
        body: JSON.stringify(data)
      })
      .then(r => r.json())
      .then(d => showStatus('Config saved!', 'success'));
    }
    
    document.getElementById('mode').addEventListener('change', (e) => {
      document.getElementById('clientSettings').style.display = 
        e.target.value === 'client' ? 'block' : 'none';
    });
    fetch('/api/config')
      .then(r => r.json())
      .then(d => {
        document.getElementById('deviceName').value = d.deviceName;
        document.getElementById('defaultDelay').value = d.defaultDelay || 100;
        document.getElementById('mode').value = d.apMode ? 'ap' : 'client';
        document.getElementById('ssid').value = d.ssid || '';
        document.getElementById('password').value = d.password || '';
        if (!d.apMode) document.getElementById('clientSettings').style.display = 'block';
      });
    
    refreshScripts();
  </script>
</body>
</html>
  )";
  
  server.send(200, "text/html", html);
}

void handleGetConfig() {
  loadConfig();
  StaticJsonDocument<512> doc;
  doc["deviceName"] = config.deviceName;
  doc["apMode"] = config.apMode;
  doc["ssid"] = config.ssid;
  doc["password"] = config.password;
  doc["apChannel"] = config.apChannel;
  doc["defaultDelay"] = config.defaultDelay;
  
  String response;
  serializeJson(doc, response);
  server.send(200, "application/json", response);
}

void handleSaveConfig() {
  if (server.hasArg("plain")) {
    StaticJsonDocument<512> doc;
    deserializeJson(doc, server.arg("plain"));
    
    strcpy(config.deviceName, doc["deviceName"] | "RubberDucky");
    strcpy(config.ssid, doc["ssid"] | "");
    strcpy(config.password, doc["password"] | "");
    config.apMode = doc["apMode"] | true;
    config.apChannel = doc["apChannel"] | 6;
    config.defaultDelay = doc["defaultDelay"] | 100;
    
    saveConfig();
    
    StaticJsonDocument<128> response;
    response["message"] = "Configuration saved. Rebooting...";
    String jsonStr;
    serializeJson(response, jsonStr);
    server.send(200, "application/json", jsonStr);
    
    delay(1000);
    ESP.restart();
  }
}

void handleGetScripts() {
  StaticJsonDocument<1024> doc;
  JsonArray scripts = doc.createNestedArray("scripts");
  
  File root = SPIFFS.open("/scripts");
  File file = root.openNextFile();
  
  while (file) {
    if (!file.isDirectory()) {
      scripts.add(file.name());
    }
    file = root.openNextFile();
  }
  
  String response;
  serializeJson(doc, response);
  server.send(200, "application/json", response);
}

void handleGetScriptContent() {
  if (server.hasArg("name")) {
    String name = server.arg("name");
    String path = "/scripts/" + name;
    String content = readFile(path.c_str());
    server.send(200, "text/plain", content);
  } else {
    server.send(400, "text/plain", "Missing name parameter");
  }
}
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
void loop() {
  server.handleClient();
  delay(10);
}

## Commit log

2026-06-05 added CAD files
    [Full_Rubber_Ducky.f3z]
2026-06-05 added PCB/KiCad files
    [Rubber Ducky.kicad_pcb, Rubber Ducky.kicad_sch, bom.csv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]
2026-06-07 added production files
    [BOM_LCSC.xls, designators.csv, positions.csv]
2026-06-07 added BOM
    [BOM.csv]
2026-06-07 Update README with assembly instructions and BOM
    Added detailed instructions for assembly and a bill of materials (BOM) with estimated costs.
